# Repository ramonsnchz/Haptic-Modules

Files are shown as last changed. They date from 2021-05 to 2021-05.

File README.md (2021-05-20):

# Haptic Modules

### Overview

The haptic modules included in this repository produce the most types of haptic sensations, namely, vibrotactile, skin-stretch, and probing haptic feedback. This repository contains the CAD files, Arduino scripts, and Python scripts needed to build and customize the haptic modules. Instructions on how to make the module adhesive are also included.

Before downloading any Arduino or Python code, please follow this tutorial [ESP8266 and Python Communication For Noobs](https://www.instructables.com/ESP8266-and-Python-Communication-ForNoobs/) and install the "ESP_MICRO.h" on your ESP8266 Esp-03.  Note: Make sure that your ESP8266 and your computer are on the same network!

More information about the modules can be found in our paper which will be published in the IEEE World Haptics Conference 2021 (link coming soon).
**If you use anything from this repository, please cite "Modular  Haptic  Feedback  for  Rapid  Prototyping  of  Tactile  Displays".**

### Materials

**All modules require the following:**
- WiFi module ([ESP8266 Esp-03](https://www.amazon.com/ESP8266-ESP-03-Wireless-Transceiver-Receive/dp/B00YHIGR62))
- 3.3 voltage regulator ([Adafruit 2745](https://www.adafruit.com/product/2745))
- [3.7V and 290mAh battery](https://tinycircuits.com/products/lithium-ion-polymer-battery-3-7v-290mah) to power the voltage regulator
- An adhesive made following [these instructions]("Ecoflex Adhesive Procedure") and using these skin-safe materials from Smooth-On (note that trial size units are plenty of material):
	- [Ecoflex Gel](https://www.smooth-on.com/products/ecoflex-gel/)
	- [Slacker](https://www.smooth-on.com/products/slacker/)
	- [Ecoflex 00-10](https://www.smooth-on.com/products/ecoflex-00-10/)

**Vibrotactile module:**
- 2222a transistor
- 2k Ohm resistor
- ERM Motor: [TOTOT Mini-Vibration Motors 10mm x 2.7mm](https://www.amazon.com/TOTOT-Vibration-Button-Type-Vibrating-Appliances/dp/B07M5GN1YD)
- [3.7V and 150mAh battery](https://tinycircuits.com/products/lithium-ion-polymer-battery-3-7v-150mah)

These components allow us to make our own motor driver, similar to [this article](https://www.electronicsforu.com/electronics-projects/pancake-vibration-motors).

**Skin-stretch modules:**
- DC motor driver ([Adafruit DRV8871](https://www.adafruit.com/product/3190))
- Low Power 100:1 micro metal gear motor ([Polulu 2204](https://www.pololu.com/product/2204))
- Magnetic encoder pair kit for micro metal gearmotors([Pololu 3081](https://www.pololu.com/product/3081))
- Two [3.7V and 290mAh batteries](https://tinycircuits.com/products/lithium-ion-polymer-battery-3-7v-290mah) in series to power the Geared DC motor

Note that *each* of the skin-stretch modules (Slider, Twister, and Rocker) require the above materials.

**Probing module:**
- DC motor driver ([Adafruit DRV8871](https://www.adafruit.com/product/3190))
- Voice coil actuator ([Tectonic Elements TEAX19CO1-8](https://www.parts-express.com/Tectonic-TEAX19C01-8-19mm-Metal-Cup-Exciter-8-Ohm-297-208))
- Two [3.7V and 1000mAh batteries](https://tinycircuits.com/products/lithium-ion-polymer-battery-3-7v-1000mah) in series to power the voice coil

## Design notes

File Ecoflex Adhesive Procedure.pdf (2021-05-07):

Materials
- Ecoflex 00-10
- Ecoflex Gel
- Ecoflex Slacker
- Mixing cups and sticks
- Gloves
- 3D printed mold
- The use of a mold release agent is recommended for an easier removal of the molded adhesive.

Procedure
1. On a mixing cup, using the Ecoflex Gel, mix 1-part A and 1-part B with 20% (w/w) Ecoflex Slacker.
2. Mix the Ecoflex Gel and Ecoflex Slacker together (about 1 minute).
3. Apply a coating of a mold release agent to the 3D printed mold.
4. Make a mark on the mold that represents a depth of 1mm, and pour the Ecoflex Gel and Slacker mixture into the molds up to the 1mm mark.
5. Let cure for 2 hours.
6. Now make the mixture for the second layer of Ecoflex 00-30. On a mixing cup, pour 1 part A and 1-part B of Ecoflex 00-10 together and stir well (about 1 minute).
7. Mark the desired thickness for the Ecoflex 00-10 layer on the mold (1mm is sufficient for good adhesion).
8. Pour 1 part A and 1-part B of Ecoflex 00-10 together and stir well (about 1 minute)
9. Pour the Ecoflex 00-10 mixture into the molds up to the mark.
10. Let cure for 4 hours at room temperature.
11. Carefully remove the molded adhesive and the module.

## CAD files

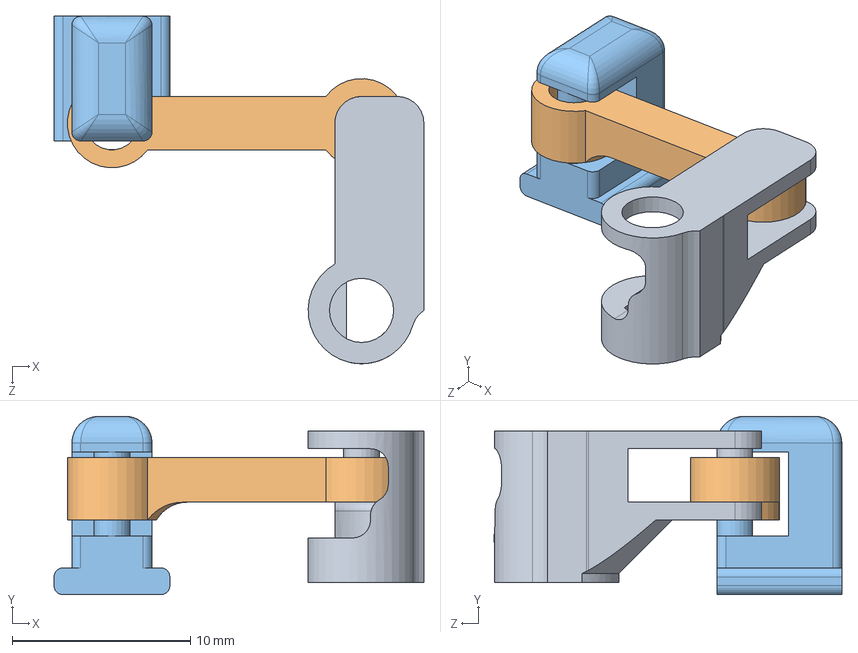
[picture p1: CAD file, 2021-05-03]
Slider Files/CADs/Assembly_Arm_12mm_14mm.SLDASM
20.8 x 10.0 x 19.5 mm
Slider_Gear_Arm_12mm
Arm
Slider

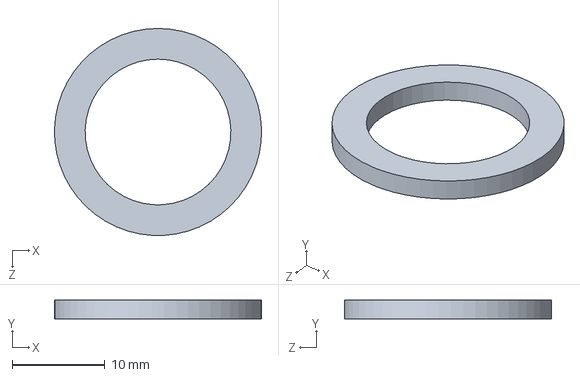
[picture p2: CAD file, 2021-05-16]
Probing Files/CADs/attachmentcircle.SLDPRT
22.3 x 2.00 x 22.3 mm

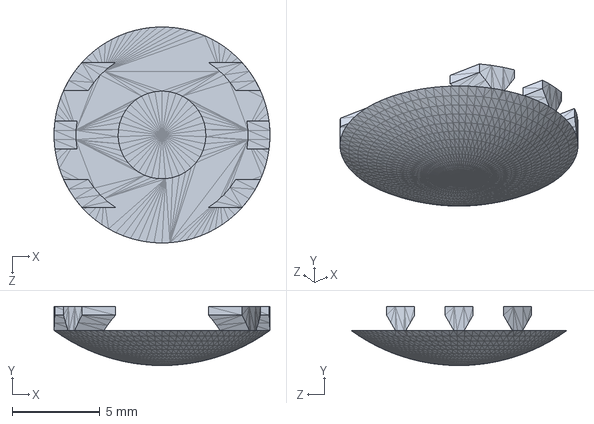
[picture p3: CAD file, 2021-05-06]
Rocker Files/CADs/springRocker_tactor.SLDPRT
12.3 x 3.37 x 12.3 mm

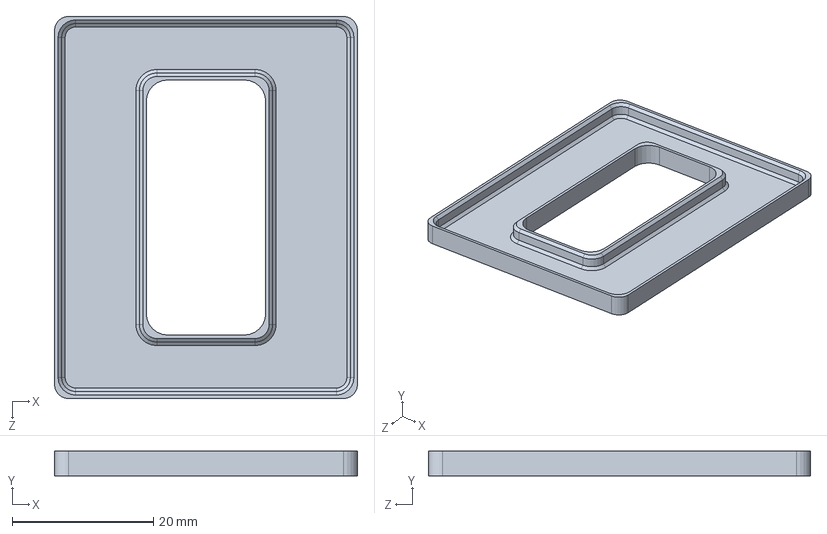
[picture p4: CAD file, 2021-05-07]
Slider Files/CADs/Slider_Mold_Base.SLDPRT
42.9 x 3.50 x 54.1 mm

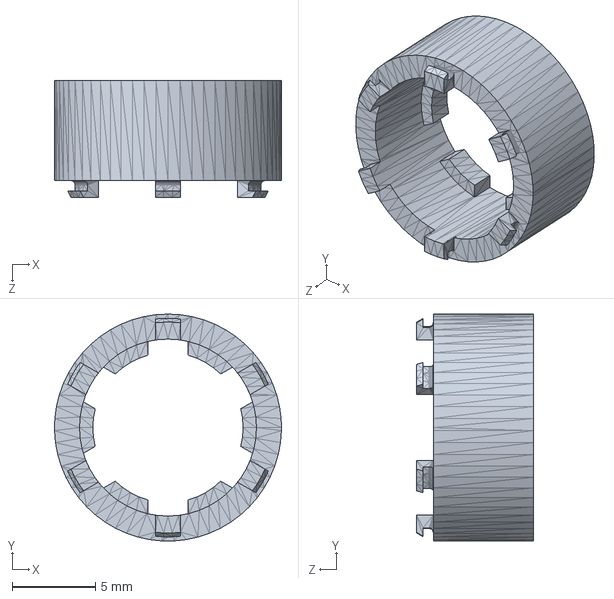
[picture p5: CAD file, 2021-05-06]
Twister Files/CADs/springTwister_shaft.SLDPRT
13.6 x 13.6 x 7.00 mm

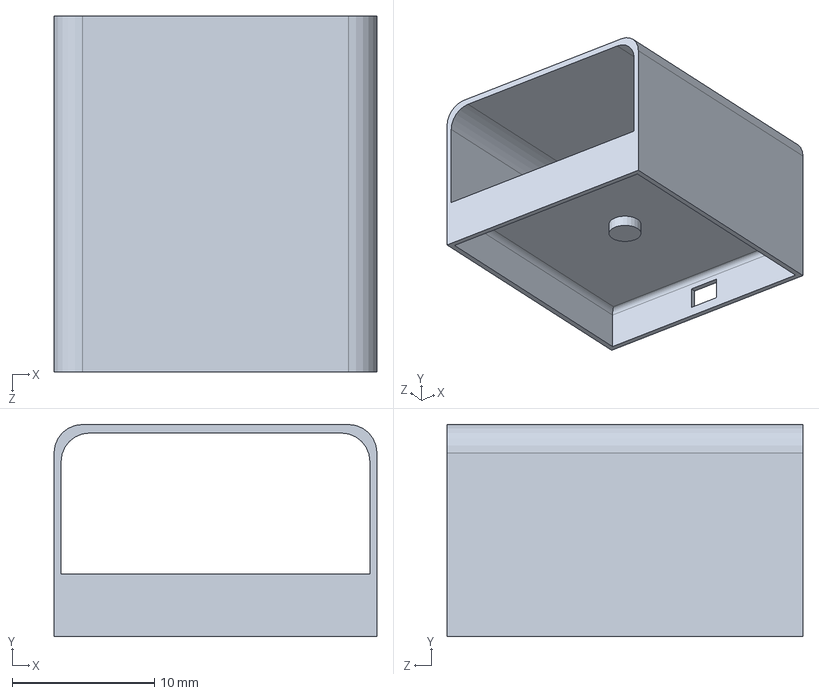
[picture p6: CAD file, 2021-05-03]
Vibrotactile Files/CADs/ERM_Holder_2Battery.SLDPRT
22.7 x 14.9 x 25.0 mm

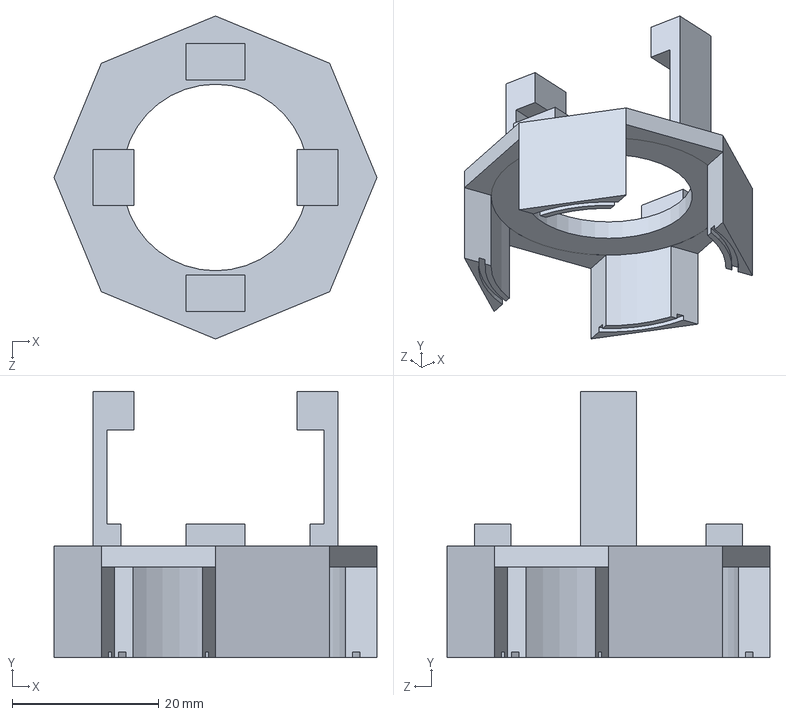
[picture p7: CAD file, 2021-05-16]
Probing Files/CADs/vchousing2.SLDPRT
44.0 x 36.2 x 44.0 mm

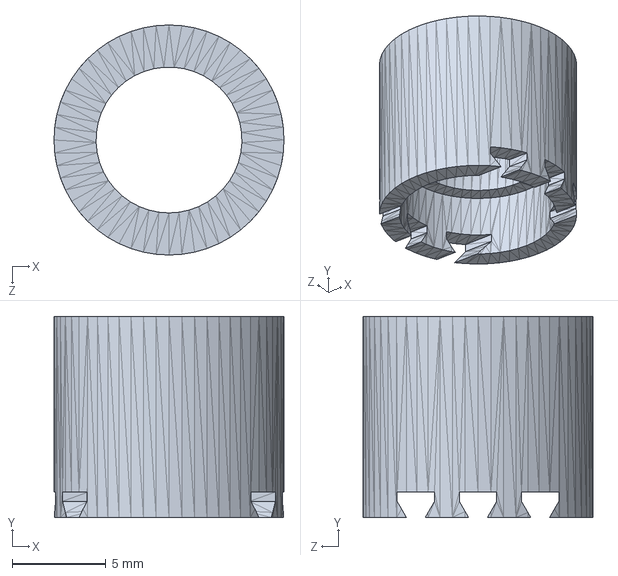
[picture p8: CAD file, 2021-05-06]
Rocker Files/CADs/springRocker_shaft.SLDPRT
12.3 x 10.8 x 12.3 mm

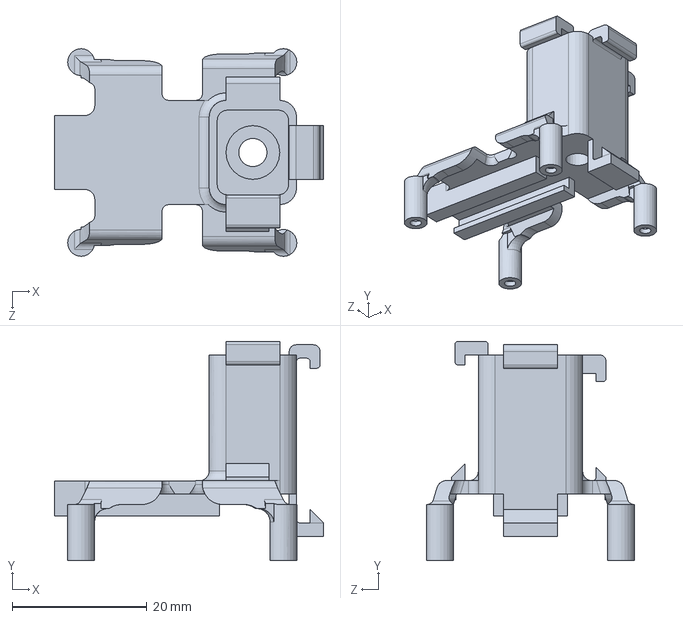
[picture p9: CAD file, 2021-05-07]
Slider Files/CADs/Skin_Stretch_Crank_Module.SLDPRT
40.0 x 32.6 x 30.9 mm

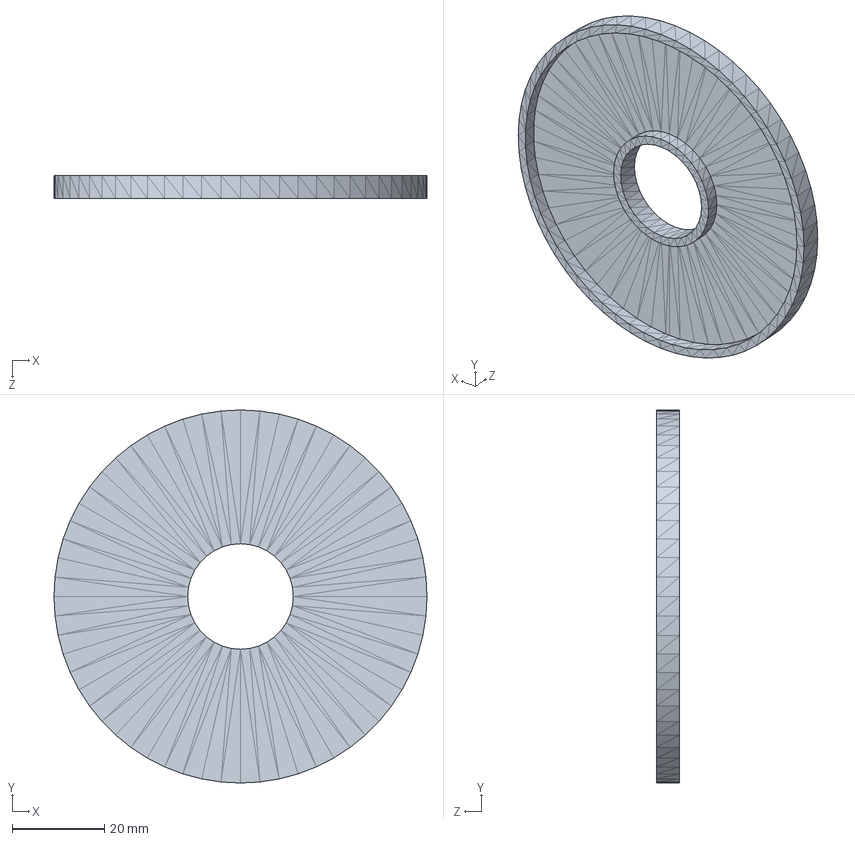
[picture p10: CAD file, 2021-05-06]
Twister Files/CADs/Twister_Silicone_Mold.SLDPRT
80.9 x 80.9 x 5.00 mm

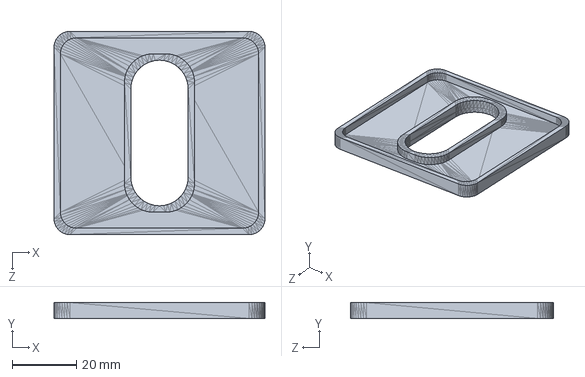
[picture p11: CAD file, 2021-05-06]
Rocker Files/CADs/Rocker_Mold.SLDPRT
65.9 x 5.00 x 63.5 mm

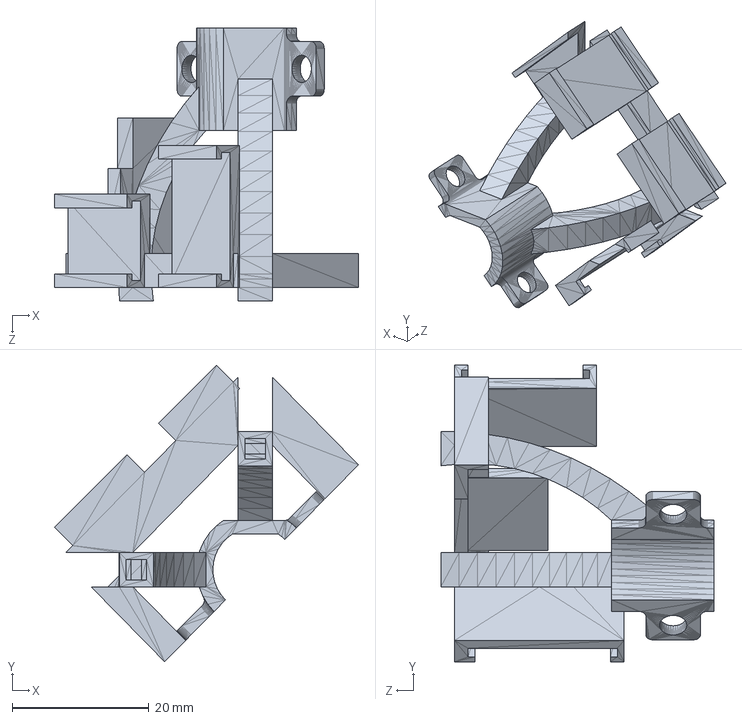
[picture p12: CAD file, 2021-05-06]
Twister Files/CADs/springTwister_Body.SLDPRT
44.5 x 43.4 x 40.0 mm

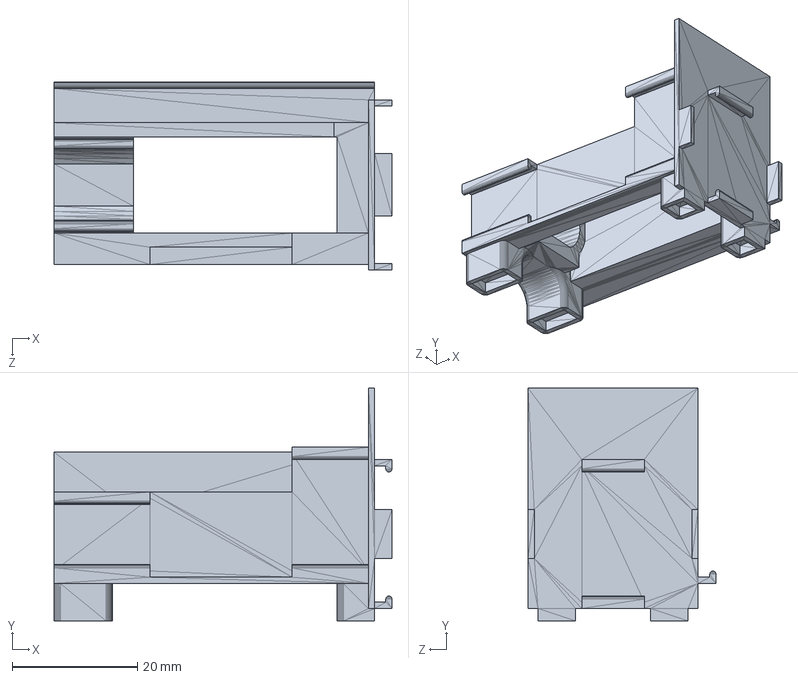
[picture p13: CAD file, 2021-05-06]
Rocker Files/CADs/Rocker_Housing.SLDPRT
54.0 x 37.2 x 30.1 mm

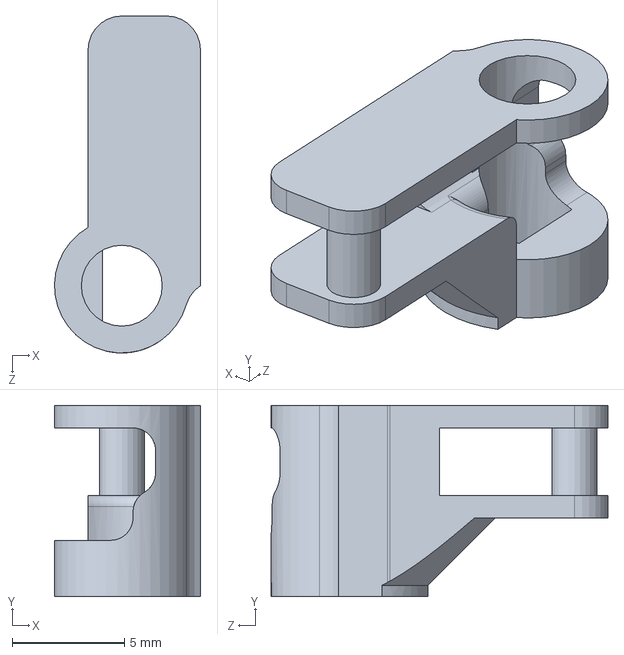
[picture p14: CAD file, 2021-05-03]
Slider Files/CADs/Slider_Gear_Arm_12mm.SLDPRT
6.50 x 8.50 x 15.0 mm

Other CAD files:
Twister Files/CADs/springTwister_tactor.SLDPRT
Slider Files/CADs/Slider.SLDPRT
Slider Files/CADs/Arm.SLDPRT

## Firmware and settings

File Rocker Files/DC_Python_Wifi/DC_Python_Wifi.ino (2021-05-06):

#include "ESP_MICRO.h" //Needed library to communicate with the esp8266 
int counter=0;
int pinA = 12; // This pin is the encoder pin B
int pinB = 14; // This pin is the encoder pin A
byte encoderSt=0;
int Motor_Forward = 2;
int Motor_Backward = 0;
int goal; // This is the desired position of the motor
int error;
byte sa = 0;
byte sb = 0;
byte sc = 0;
byte start_ = 0;
String action;


 void setup() { 
   Serial.begin (115200);
   start("WiFi Network","Password");// Connect to wifi, enter your details here
   pinMode (Motor_Forward,OUTPUT); 
   pinMode (Motor_Backward,OUTPUT);
   delay(50);
 } 
 
void loop()
{
if (start_!=1){
  waitUntilNewReq();    // Waits until a new request from python come
  action = getPath();
  action.remove(0,1);
  goal = action.toInt();
}
start_=1;
byte a = digitalRead( pinA );
byte b = digitalRead( pinB );
byte st = (b<<1) | a;
if ( encoderSt != st ) 
{
if ( (encoderSt==0 && st==2) || (encoderSt==1 && st==0) || (encoderSt==2 && st==3) || (encoderSt==3 && st==1) ) counter-- ;
else counter++;
encoderSt = st;
}
 error = goal-counter;
 if ((error<-10) && (sb!=1)){
  digitalWrite(Motor_Forward, HIGH);
  digitalWrite(Motor_Backward, LOW);
  sb=1;
  sa=1;
 }
 else if ((error>10) && (sc!=1)){
    digitalWrite(Motor_Forward, LOW);
    digitalWrite(Motor_Backward, HIGH);
    sc=1;
    sa=1;
 }
 else if ((abs(error)<=10) && (sa==1)){
  digitalWrite(Motor_Forward, LOW);
  digitalWrite(Motor_Backward, LOW);
  delay(10);
  sb=0;
  sc=0;
  start_=0;
  goal = 0;
 }
}

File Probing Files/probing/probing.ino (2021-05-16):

#include "ESP_MICRO.h" 

//Initializing Pins that will go into the motor driver
int pin = 6; 
int pin2 = 7;
int pin3 = 8;
// We use three pins, as two pins determine direction of current and a third pin determines the amount of power sent
// This code has four conditions that responds to commands from the python scrypt via wifi
// Input 1 for 1 click, 2 for 2 clicks, 3 for 3 clicks, and 4 for vibrations at 100hz for 1 second
void setup() {
  start("Your network","Password");// Connect to wifi, enter your details here
  pinMode(pin, OUTPUT);
  pinMode(pin2, OUTPUT);
  pinMode(pin3, OUTPUT);
  Serial.begin(115200);
}

void loop() 
  {
  waitUntilNewReq();    // Waits until a new request from python come
  action = getPath();
  action.remove(0,1);
  state = action.toInt();
  if (state == 1)
  {
    digitalWrite(pin2, HIGH);
    digitalWrite(pin3, LOW);
    digitalWrite(pin, HIGH);
    delay(100);
    digitalWrite(pin2, LOW);
  }
  if (state == 2)
  {
    digitalWrite(pin2, HIGH);
    digitalWrite(pin3, LOW);
    digitalWrite(pin, HIGH);
    delay(100);
    digitalWrite(pin2, LOW);
    delay(100);
    digitalWrite(pin2, HIGH);
    digitalWrite(pin3, LOW);
    digitalWrite(pin, HIGH);
    delay(100);
    digitalWrite(pin2, LOW);
  }
  if (state == 3)
  {
    digitalWrite(pin2, HIGH);
    digitalWrite(pin3, LOW);
    digitalWrite(pin, HIGH);
    delay(100);
    digitalWrite(pin2, LOW);
    delay(100);
    digitalWrite(pin2, HIGH);
    digitalWrite(pin3, LOW);
    digitalWrite(pin, HIGH);
    delay(100);
    digitalWrite(pin2, LOW);
    delay(100);
    digitalWrite(pin2, HIGH);
    digitalWrite(pin3, LOW);
    digitalWrite(pin, HIGH);
    delay(100);
    digitalWrite(pin2, LOW);
  }
  if (state == 4)
  {
    for(int i=0; i<100; i++){
      digitalWrite(pin, HIGH);
      digitalWrite(pin2, HIGH);
      digitalWrite(pin3, LOW);
      delay(5);
      digitalWrite(pin, LOW);
      delay(5);
    }
  }
}

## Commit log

2021-05-03 Haptic Modules Files
    This contains the files needed to start working towards creating your own haptic sensations.
    [Arm.SLDPRT, Assembly_Arm_12mm_14mm.SLDASM, ERM_Holder_2Battery.SLDPRT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]
2021-05-06 Adding all needed files
    [Rocker_Housing.SLDPRT, Rocker_Mold.SLDPRT, Twister_Silicone_Mold.SLDPRT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]
2021-05-07 Slider Module Body
    [Skin_Stretch_Crank_Module.SLDPRT]
2021-05-07 Sliders Mold
    [Slider_Mold_Base.SLDPRT]
2021-05-16 Startup code
    [attachmentcircle.SLDPRT, vchousing2.SLDPRT]
